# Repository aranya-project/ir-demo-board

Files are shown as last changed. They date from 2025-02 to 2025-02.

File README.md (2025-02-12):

# IR Demo FeatherWing

This is a carrier board for an Adafruit Feather device, designed specifically
for the ESP32-S3 Feather. It breaks out two UARTs into IR transceivers, and SPI
to a microSD slot.

## Board View

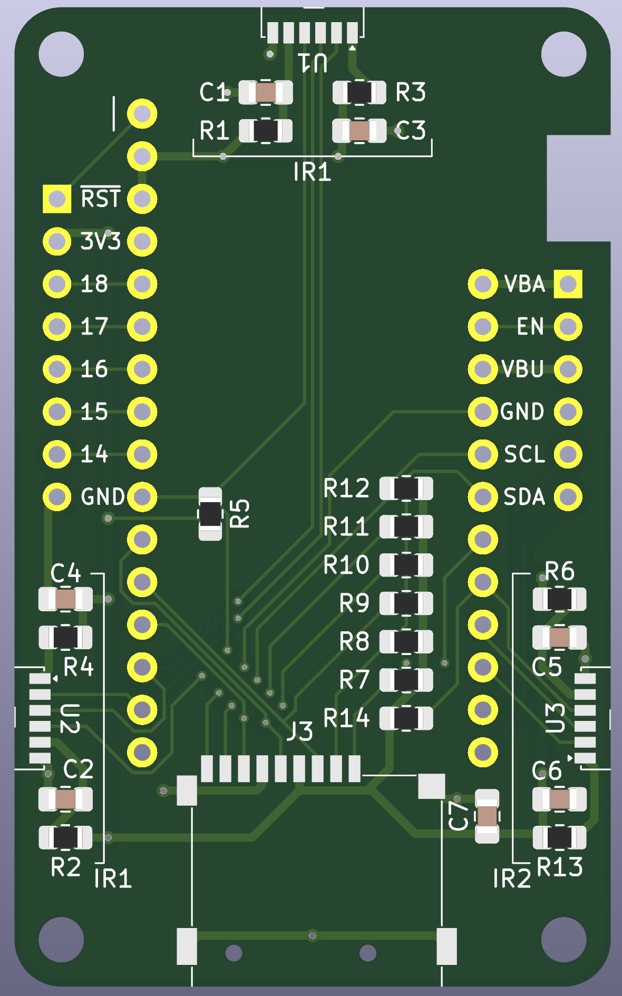
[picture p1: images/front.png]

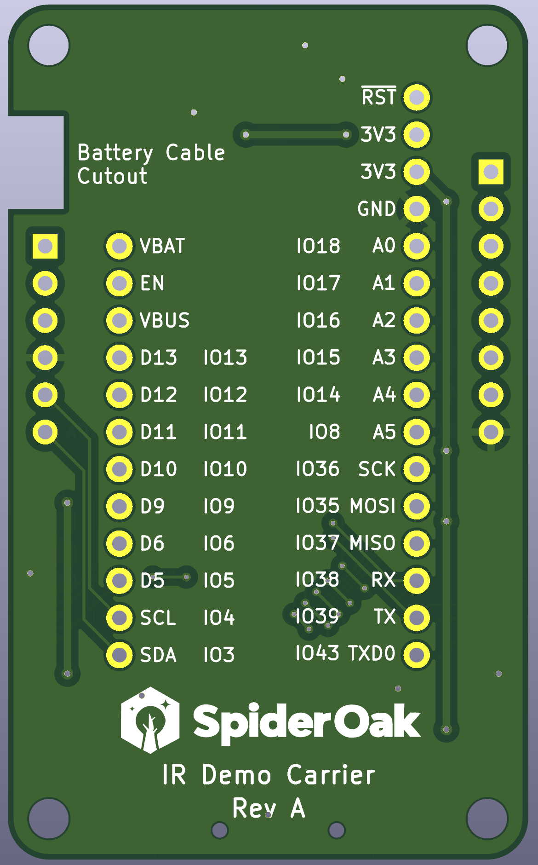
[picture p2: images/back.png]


## Assembly Options

There are three sets of components for the IR transceivers, but only two
can be used. The sections marked IR1 are shared, connected to UART1, and
only one section needs to be populated. The section marked IR2 is
connected to UART2.

Technically, the only components that have to be installed are one
transceiver and two links to power them (across R1/R3 on the top, R2/R4
on the left, and R6/R13 on the right). The capacitors improve stability
but aren't strictly required. The other resistors are pull-ups for the
SD lines (recommended but makes little practical difference) and
pull-ups for the IR shutdown (only really necessary if you plan on
shutting down the CPU)

## IR Transceivers

IR1 is connected to UART1 on the standard Feather TX/RX pins, which are
on GPIOs 39 and 38, respectively. IR2 is connected to UART2 on GPIOs 5
and 6. Each transceiver has an active low enable pin that is by default
pulled high. These are on GPIOs 8 and 9 for IR1 and IR2.

Enabling IrDA mode requires setting `UART_IRDA_EN` in `UART_CONF0_REG`.
Additionally, to transmit, you need to set `UART_IRDA_TX_EN`. By
default, IrDA mode is half duplex, and `UART_IRDA_TX_EN` needs to be
toggled to switch between transmit and receive modes. To enable both
transmit and receive at the same time, which will echo all transmitted
data through the RX line, set `UART_IRDA_DPLX`.

For reasons I don't understand, the only thing that can be set via IDF
APIs is enabling IrDA mode. All of the other IrDA settings are not
available via IDF APIs, so you will likely have to twiddle the registers
directly. In C, this can be done by including `soc/uart_struct.h` and
using the bitfield structs provided. i.e.

```
UART1.conf0.irda_dplx = 1;
```

### Pin Summary (IR1 on UART1)

| GPIO Pin | Function |
|---|---|
| 39 | Transmit |
| 38 | Receive |
| 8 | Enable (active low) |

### Pin Summary (IR2 on UART2)

| GPIO Pin | Function |
|---|---|
| 5 | Transmit |
| 6 | Receive |
| 9 | Enable (active low) |

## Micro SD

The SD card is connected to SPI such that it should be usable directly
through the IOMUX on IOs 35, 36, and 37. CS is connected to GPIO 11.
Card detect is connected to GPIO 13.

Additionally, DAT1 and DAT2 (only used in SD mode) are connected to
GPIOs 12 and 10, respectively, so you should theoretically be able to
enable 4-bit SD through the SD/MMC controller.

### Pin Summary (SPI mode)

| GPIO Pin | Function |
|---|---|
| 36 | SCK |
| 35 | MOSI |
| 37 | MISO |
| 11 | CS |

### Pin Summary (SD 1-bit mode)

| GPIO Pin | Function |
|---|---|
| 36 | CLK |
| 35 | CMD |
| 37 | DAT0 |
| 11 | CD |

### Pin Summary (SD 4-bit mode)

| GPIO Pin | Function |
|---|---|
| 36 | CLK |
| 35 | CMD |
| 37 | DAT0 |
| 12 | DAT1 |
| 10 | DAT2 |
| 11 | DAT3 |

## Headers

 GPIOs 14-18 are unused and are broken out for futher expansion. The I2C
 lines are also available, as well as VBATT, VBUS, 3V3, GND, EN, and
 ~RST.

## Mechanical

The board is 1.4 inches wide and 2.3 inches tall (35.56 x 58.42mm). The
component sizes should be similar to their footprint outlines, giving it
a maximum horizontal extent of 1.51" (38.354mm) with both side IR
transceivers installed, and a maximum vertical extent of 2.51"
(63.754mm) with the top transceiver installed and an SD card inserted.

Four mounting holes on the corners are sized for M2.5 screws. They are
0.11" (2.794mm) from the edges, which is also the corner radius.

A 0.15x0.25 inch (3.81x6.35mm) cutout is provided near the Feather's
battery connector in the upper right. This allows any battery cables to
be routed below the board even if the board is mounted flush against a
case.

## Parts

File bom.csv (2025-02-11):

Reference | Value | Footprint | Qty | DNP | MPN
A1 | Adafruit_Feather_ESP32-S3 | Module:Adafruit_Feather | 1 |  | Adafruit 5477
C1,C5,C7 | 1u | Capacitor_SMD:C_0805_2012Metric_Pad1.18x1.45mm_HandSolder | 3 |  | C0805C105Z4VACTU
C3,C6 | 4.7u | Capacitor_SMD:C_0805_2012Metric_Pad1.18x1.45mm_HandSolder | 2 |  | CL21A475KOFNNNE
J3 | Micro SD | custom8:MSD-4-A | 1 |  | SameSky MSD-4-A
R1,R6 | 47 | Resistor_SMD:R_0805_2012Metric_Pad1.20x1.40mm_HandSolder | 2 |  | WR08X470 JTL
R3,R13 | 10 | Resistor_SMD:R_0805_2012Metric_Pad1.20x1.40mm_HandSolder | 2 |  | WR08X100 JTL
R5,R7,R8,R9,R10,R11,R12,R14 | 47K | Resistor_SMD:R_0805_2012Metric_Pad1.20x1.40mm_HandSolder | 8 |  | RMCF0805FT47K0
U1,U3 | TFBS4711 | custom8:TFBS4711 | 2 |  | Vishay TFBS4711

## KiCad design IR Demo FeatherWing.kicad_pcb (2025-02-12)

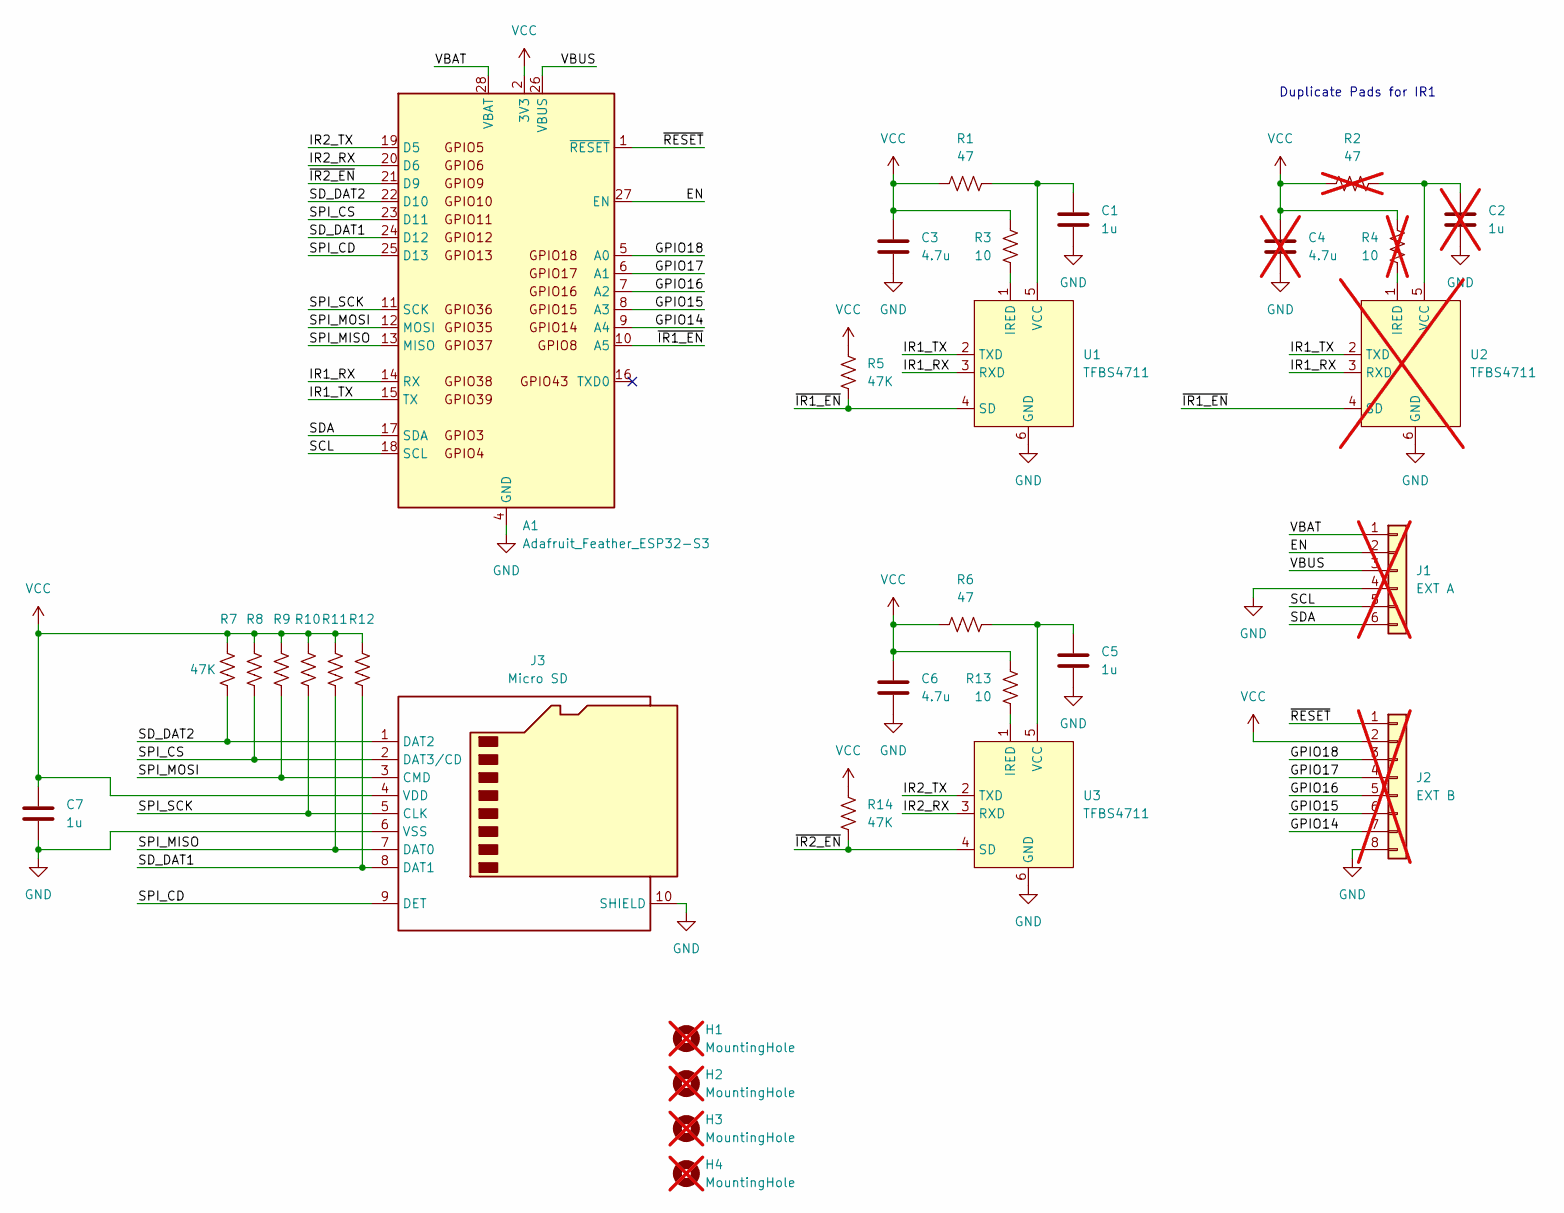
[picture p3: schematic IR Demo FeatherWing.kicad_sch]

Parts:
A1: Adafruit_Feather_ESP32-S3; Adafruit_Feather; MPN Adafruit 5477
C1, C5, C7: 1u; C_0805_2012Metric_Pad1.18x1.45mm_HandSolder; MPN C0805C105Z4VACTU
C2: 1u; C_0805_2012Metric_Pad1.18x1.45mm_HandSolder; MPN C0805C105Z4VACTU; not fitted
C3, C6: 4.7u; C_0805_2012Metric_Pad1.18x1.45mm_HandSolder; MPN CL21A475KOFNNNE
C4: 4.7u; C_0805_2012Metric_Pad1.18x1.45mm_HandSolder; MPN CL21A475KOFNNNE; not fitted
H1, H2, H3, H4: MountingHole; MountingHole_2.7mm_M2.5; not fitted
J1: EXT A; PinHeader_1x06_P2.54mm_Vertical; not fitted
J2: EXT B; PinHeader_1x08_P2.54mm_Vertical; not fitted
J3: Micro SD; MSD-4-A; MPN SameSky MSD-4-A
R1, R6: 47; R_0805_2012Metric_Pad1.20x1.40mm_HandSolder; MPN WR08X470 JTL
R2: 47; R_0805_2012Metric_Pad1.20x1.40mm_HandSolder; MPN WR08X470 JTL; not fitted
R3, R13: 10; R_0805_2012Metric_Pad1.20x1.40mm_HandSolder; MPN WR08X100 JTL
R4: 10; R_0805_2012Metric_Pad1.20x1.40mm_HandSolder; MPN WR08X100 JTL; not fitted
R5, R7, R8, R9, R10, R11, R12, R14: 47K; R_0805_2012Metric_Pad1.20x1.40mm_HandSolder; MPN RMCF0805FT47K0
U1, U3: TFBS4711; MPN Vishay TFBS4711
U2: TFBS4711; MPN Vishay TFBS4711; not fitted

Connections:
/EN: A1.27 (EN), J1.2
/GPIO14: A1.9 (A4), J2.7
/GPIO15: A1.8 (A3), J2.6
/GPIO16: A1.7 (A2), J2.5
/GPIO17: A1.6 (A1), J2.4
/GPIO18: A1.5 (A0), J2.3
/IR1_RX: A1.14 (RX), U1.3 (RXD), U2.3 (RXD)
/IR1_TX: A1.15 (TX), U1.2 (TXD), U2.2 (TXD)
/IR2_RX: A1.20 (D6), U3.3 (RXD)
/IR2_TX: A1.19 (D5), U3.2 (TXD)
/SCL: A1.18 (SCL), J1.5
/SDA: A1.17 (SDA), J1.6
/SD_DAT1: A1.24 (D12), J3.8 (DAT1), R12.2
/SD_DAT2: A1.22 (D10), J3.1 (DAT2), R7.2
/SPI_CD: A1.25 (D13), J3.9 (DET)
/SPI_CS: A1.23 (D11), J3.2 (DAT3/CD), R8.2
/SPI_MISO: A1.13 (MISO), J3.7 (DAT0), R11.2
/SPI_MOSI: A1.12 (MOSI), J3.3 (CMD), R9.2
/SPI_SCK: A1.11 (SCK), J3.5 (CLK), R10.2
/VBAT: A1.28 (VBAT), J1.1
/VBUS: A1.26 (VBUS), J1.3
/~IR1_EN: A1.10 (A5), R5.2, U1.4 (SD), U2.4 (SD)
/~IR2_EN: A1.21 (D9), R14.2, U3.4 (SD)
/~RESET: A1.1 (~RESET), J2.1
GND: A1.4 (GND), C1.2, C2.2, C3.2, C4.2, C5.2, C6.2, C7.2, J1.4, J2.8, J3.6 (VSS), J3.10 (SHIELD), U1.6 (GND), U2.6 (GND), U3.6 (GND)
unnamed: R3.2, U1.1 (IRED)
unnamed: C1.1, R1.2, U1.5 (VCC)
unnamed: R4.2, U2.1 (IRED)
unnamed: C2.1, R2.2, U2.5 (VCC)
unnamed: R13.2, U3.1 (IRED)
unnamed: C5.1, R6.2, U3.5 (VCC)
VCC: A1.2 (3V3), A1.3 (3V3), C3.1, C4.1, C6.1, C7.1, J2.2, J3.4 (VDD), R1.1, R2.1, R3.1, R4.1, R5.1, R6.1, R7.1, R8.1, R9.1, R10.1, R11.1, R12.1, R13.1, R14.1

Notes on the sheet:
Duplicate Pads for IR1

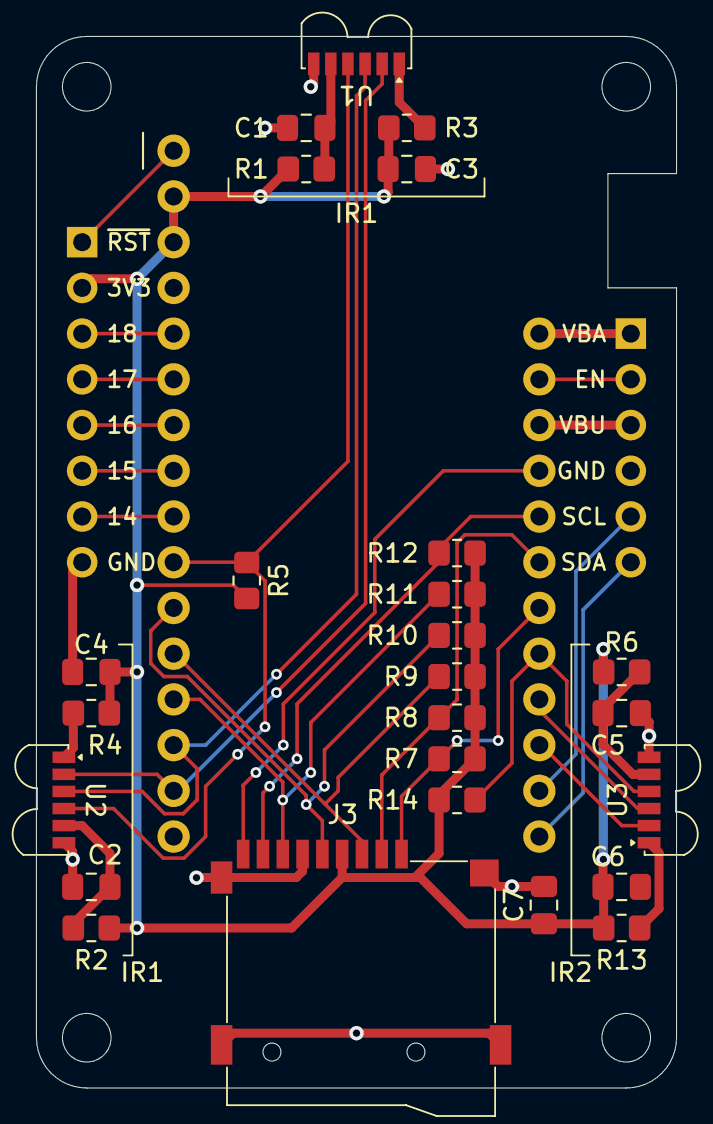
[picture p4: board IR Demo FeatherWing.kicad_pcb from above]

Board: 2 copper layers, 35.6 x 58.4 mm, 32 parts (0 on the bottom side), 32 nets.

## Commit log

2025-02-11 Rev A
    [IR Demo FeatherWing.kicad_pcb, IR Demo FeatherWing.kicad_sch]
2025-02-11 Add BOM and README
    [IR Demo FeatherWing.kicad_sch, bom.csv]
2025-02-11 Add gerbers
    [IR Demo FeatherWing-B_Cu.gbr, IR Demo FeatherWing-B_Mask.gbr, IR Demo FeatherWing-B_Paste.gbr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]
2025-02-12 Add more dimensions and mechanical description
    [IR Demo FeatherWing.kicad_pcb]
